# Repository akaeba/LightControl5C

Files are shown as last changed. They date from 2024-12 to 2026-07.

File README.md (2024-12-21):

# LightControl5C

Five microcontroller controlled output stages with an integrated voltage selectable power supply.

## Features
* five free programmable outputs
* up to 500mA per output (all 600mA max)
* voltage divider selectable output voltage
* optimized for 24V input voltage
* up to 20V output voltage
* inductive load capable
* ICSP programming interface
* 44mm x 27mm overall size

## Pinning
| Port | Usage |
| --- | --- |
| X1 | positive input supply, max. 28V, DC-only |
| X2 | negative input supply (GND) |
| X3 | ICSP programming |
| X4 | GND |
| X5 | open-drain uC output (GP0) |
| X6 | open-drain uC output (GP1) |
| X7 | open-drain uC output (GP2) |
| X8 | open-drain uC output (GP4) |
| X9 | open-drain uC output (GP5) |
| X10, X11 | positive supply for X5-X9, voltage via R<sub>FBT</sub> adjustable |

## How to build
* Get your PCB:
  - [Aisler](https://aisler.net/p/RHHJMNNA)
  - [PCBway](https://www.pcbway.com/project/shareproject/LightControl5C_13ccc4e5.html)
* Order Components from:
  - [Reichelt](/bom/LightControl5C_Reichelt.csv)
  - [Mouser](/bom/LightControl5C_Mouser.csv)

## Gallery
<tr>
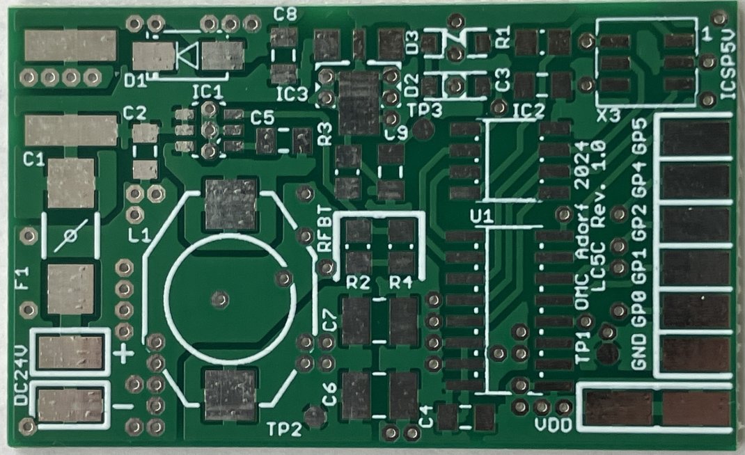
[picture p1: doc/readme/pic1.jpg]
Picture PCB Top site LightControl5C Top site
<td>  </td>
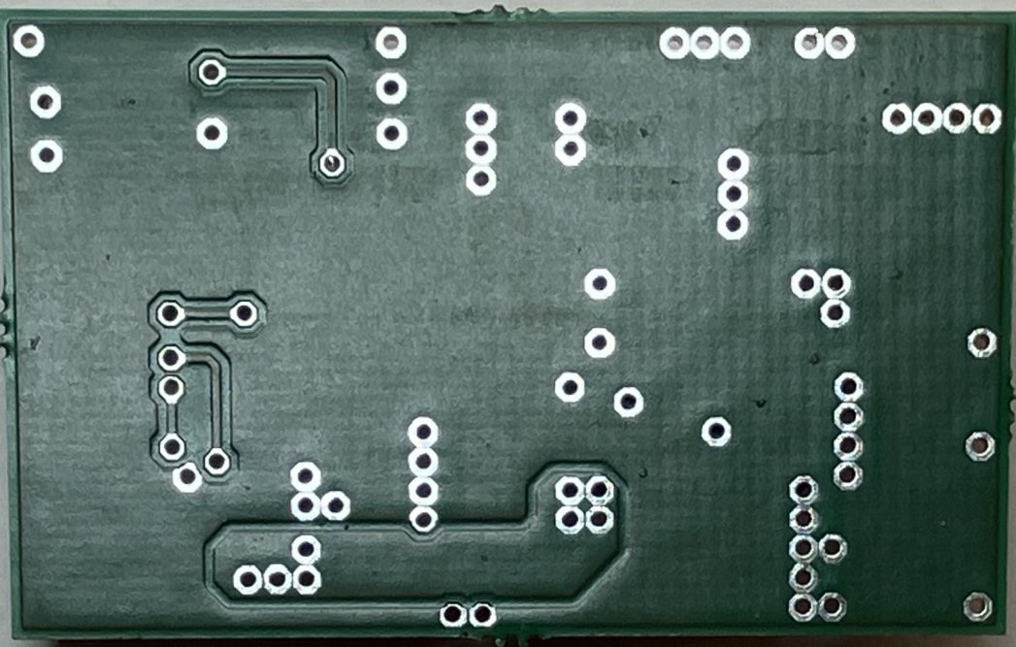
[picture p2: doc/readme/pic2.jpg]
Picture PCB Bottom site LightControl5C Bottom site
<td>  </td>
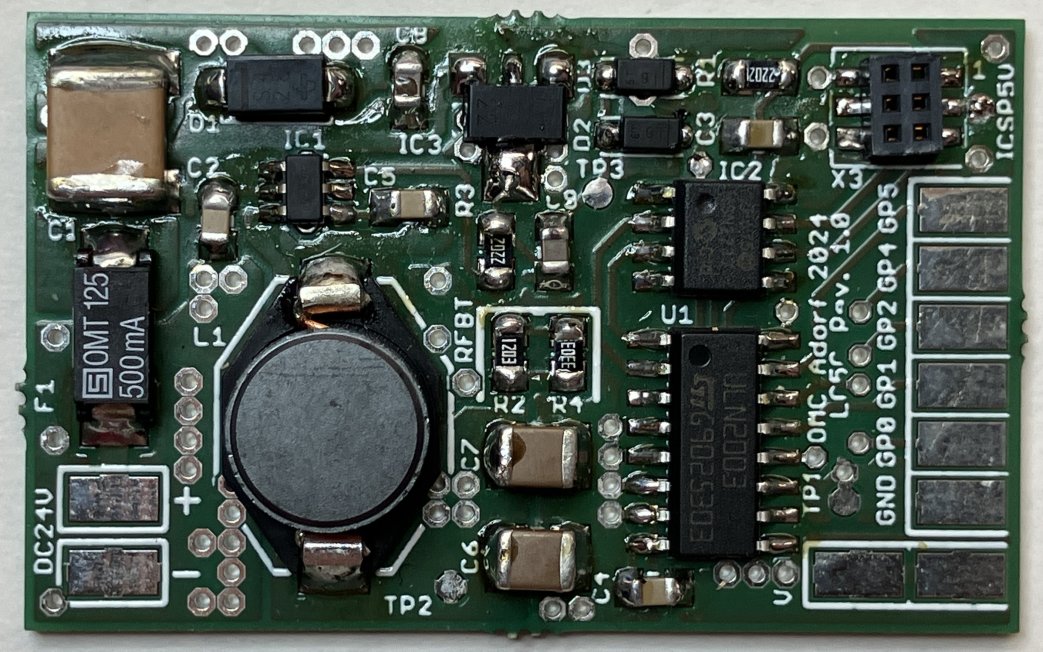
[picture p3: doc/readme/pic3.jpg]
Picture PCB with components Assembled components on LightControl5C
<td>  </td>
</tr>

## Tooling
* PCB and schematic: [Eagle 7.7](http://eagle.autodesk.com/eagle/software-versions/1)
* Compiler: [MikroC Pro for PIC 7.1](https://download.mikroe.com/setups/compilers/mikroc/pic/mikroc-pic-setup-v710.zip)
* Programmer:
  - [PicKit2 HW](https://www.microchip.com/en-us/development-tool/pg164120) - check also the clone vendors ;-)
  - [PicKit2 SW](https://ww1.microchip.com/downloads/aemDocuments/documents/OTH/ProductDocuments/SoftwareLibraries/Firmware/PICkit2v2.61.00SetupA.zip)

## References
* [LV3842: 4-V to 36-V, 600-mA, Synchronous Step-Down Converter](https://www.ti.com/lit/ds/symlink/lv3842.pdf)
* [PIC12F675: 8-Pin, Flash-Based 8-Bit CMOS Microcontrollers](https://ww1.microchip.com/downloads/aemDocuments/documents/MCU08/ProductDocuments/DataSheets/41190G.pdf)
* [ULN2003: Seven Darlington arrays](https://www.st.com/resource/en/datasheet/uln2003.pdf)
* [TPL7407LA:  30V 7-Channel Low Side Driver](https://www.ti.com/lit/ds/symlink/tpl7407la.pdf)

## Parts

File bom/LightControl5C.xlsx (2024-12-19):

Designator | Qty | Part Number | Package | Remark | Distributor
C1 | 1 | KTD500B106M55A0T00 | C2220K | SMD-Kerko, 2220, 10 µF, 50 V, 10%, MLCC | Reichelt
C2, C3, C4, C5 | 4 | 100.0nF, 0805 SMD, 50.0V | 0805 | SMD-Vielschicht-Keramikkondensator 100N, 10% | Reichelt
C6, C7 | 2 | 22.0µF, 1210 SMD, 25.0V | 1210 | Vielschicht-Kerko, 22µF, 25V, 125°C | Reichelt
C8 | 1 | 1.0µF, 0805 SMD, 50.0V | 0805 | SMD-Vielschichtkondensator G0805 - 1,0µF 50V | Reichelt
C9 | 1 | C0805C225K4RAC | 0805 | 0805, 2,2 µF, X7R, 10 %, 16V, 125°C | Reichelt
D1 | 1 | SS14-E3/61T | SMA | Schottkydiode, 40 V, 1 A, DO-214AC | Reichelt
F1 | 1 | 3404.0112.11 | OMT125 | 0,5A SMD-Sicherung, OMT-125V, träge | Reichelt
IC1 | 1 | LV3842XDBVR | SOT23-6 | 4-V to 36-V, 600mA Buck Converter in SOT-23-6 | Mouser
IC2 | 1 | PIC12F675-I/SN | SOIC8. | PIC12F675 - 8-Pin FLASH-Based 8-Bit CMOS Microcontrollers | Reichelt
 | 1 | TS78L05ACY RMG | SOT89W | Spannungsregler, fest, 5 V, SOT-89 | Reichelt
L1 | 1 | PISM-220M-04 | PISM | SMD-Power-Induktivität, PISM, Ferrit, 22µ, VDD=5V | Reichelt
R1, R3 | 2 | 22.0kΩ, 0805 SMD | 0805 | SMD-Widerstand, 0805, 22 kOhm, 125 mW, 1% | Reichelt
R2 | 1 | 120kΩ, 0805 SMD | 0805 | SMD-Widerstand, 0805, 120 kOhm, 125 mW, 1% | Reichelt
R4 | 1 | 330kΩ, 0805 SMD | 0805 | SMD-Widerstand, 0805, 330 kOhm, 125 mW, 1% | Reichelt
U1 | 1 | ULN2003D | SOIC16 | Darlington-Arrays, SO-16 | Reichelt
X3 | 1 | FLE-103-01-G-DV-TR | FLE-103 | Board to Board & Mezzanine Connectors | Mouser
D2, D3 | 2 | BAT46W | SOD123 | BAT46 - Schottky Diode | Reichelt

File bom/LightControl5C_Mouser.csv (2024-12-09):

Mouser No | Order Qty.
595-LV3842XDBVR | 1
200-FLE10301GDVTR | 1

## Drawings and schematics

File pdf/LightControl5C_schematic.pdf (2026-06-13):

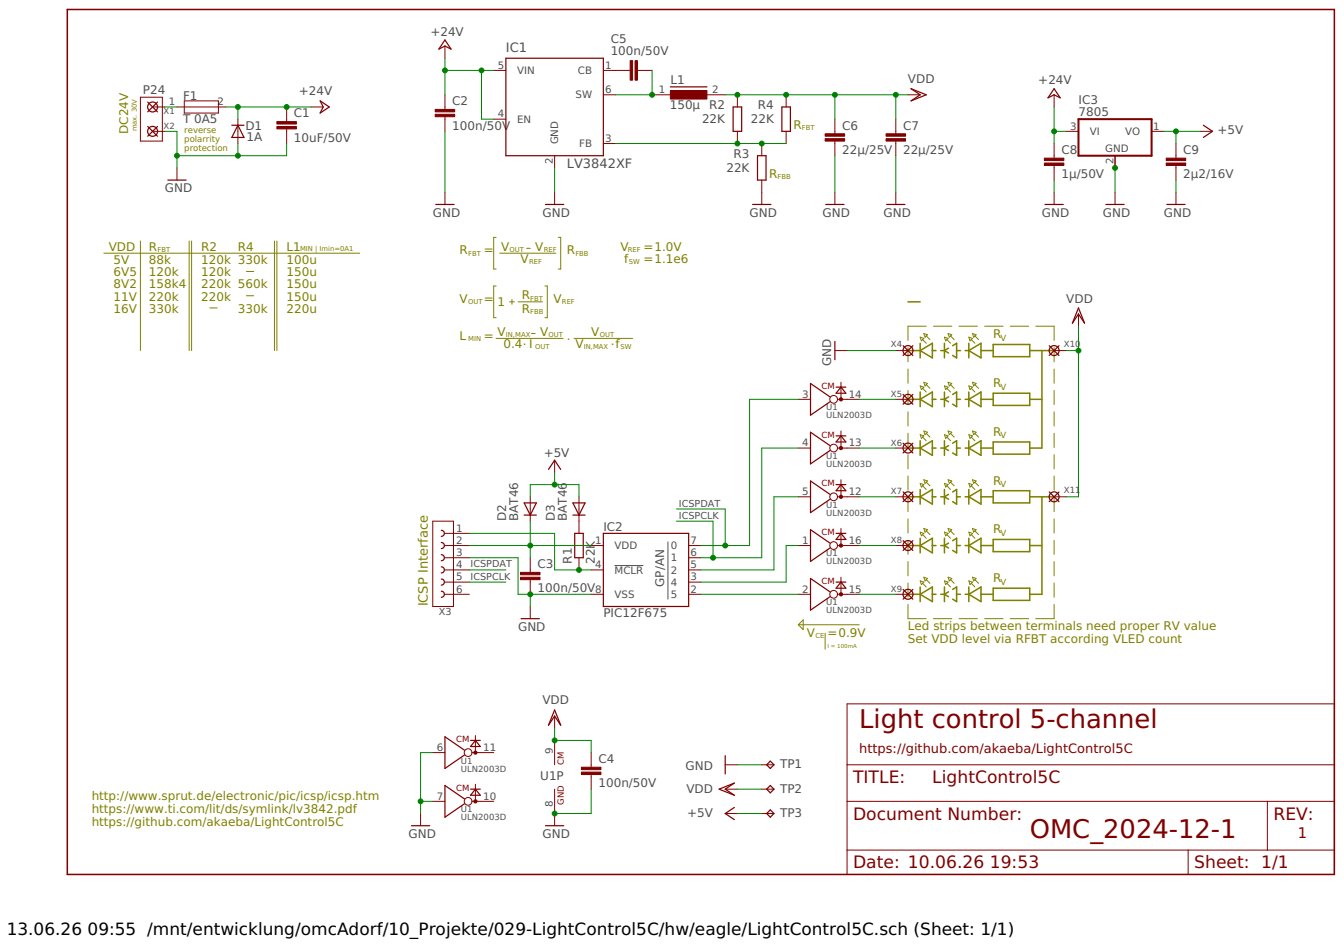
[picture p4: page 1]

reverse polarrity protection max. 30V

Led strips between terminals need proper RV value Set VDD level via RFBT according VLED count

https://github.com/akaeba/LightControl5C
TITLE:

http://www.sprut.de/electronic/pic/icsp/icsp.htm
https://www.ti.com/lit/ds/symlink/lv3842.pdf

Document Number: OMC_2024-12-1 | REV: 1

Date: 10.06.26 19:53 | Sheet: 1/1

13.06.26 09:55 /mnt/entwicklung/omcAdorf/10_Projekte/029-LightControl5C/hw/eagle/LightControl5C.sch (Sheet: 1/1)

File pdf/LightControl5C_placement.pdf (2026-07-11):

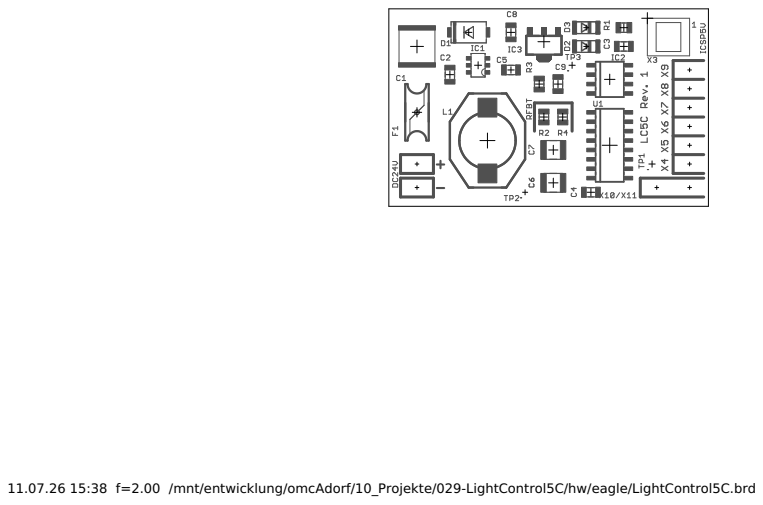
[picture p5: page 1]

11.07.26 15:38 f=2.00 /mnt/entwicklung/omcAdorf/10_Projekte/029-LightControl5C/hw/eagle/LightControl5C.brd

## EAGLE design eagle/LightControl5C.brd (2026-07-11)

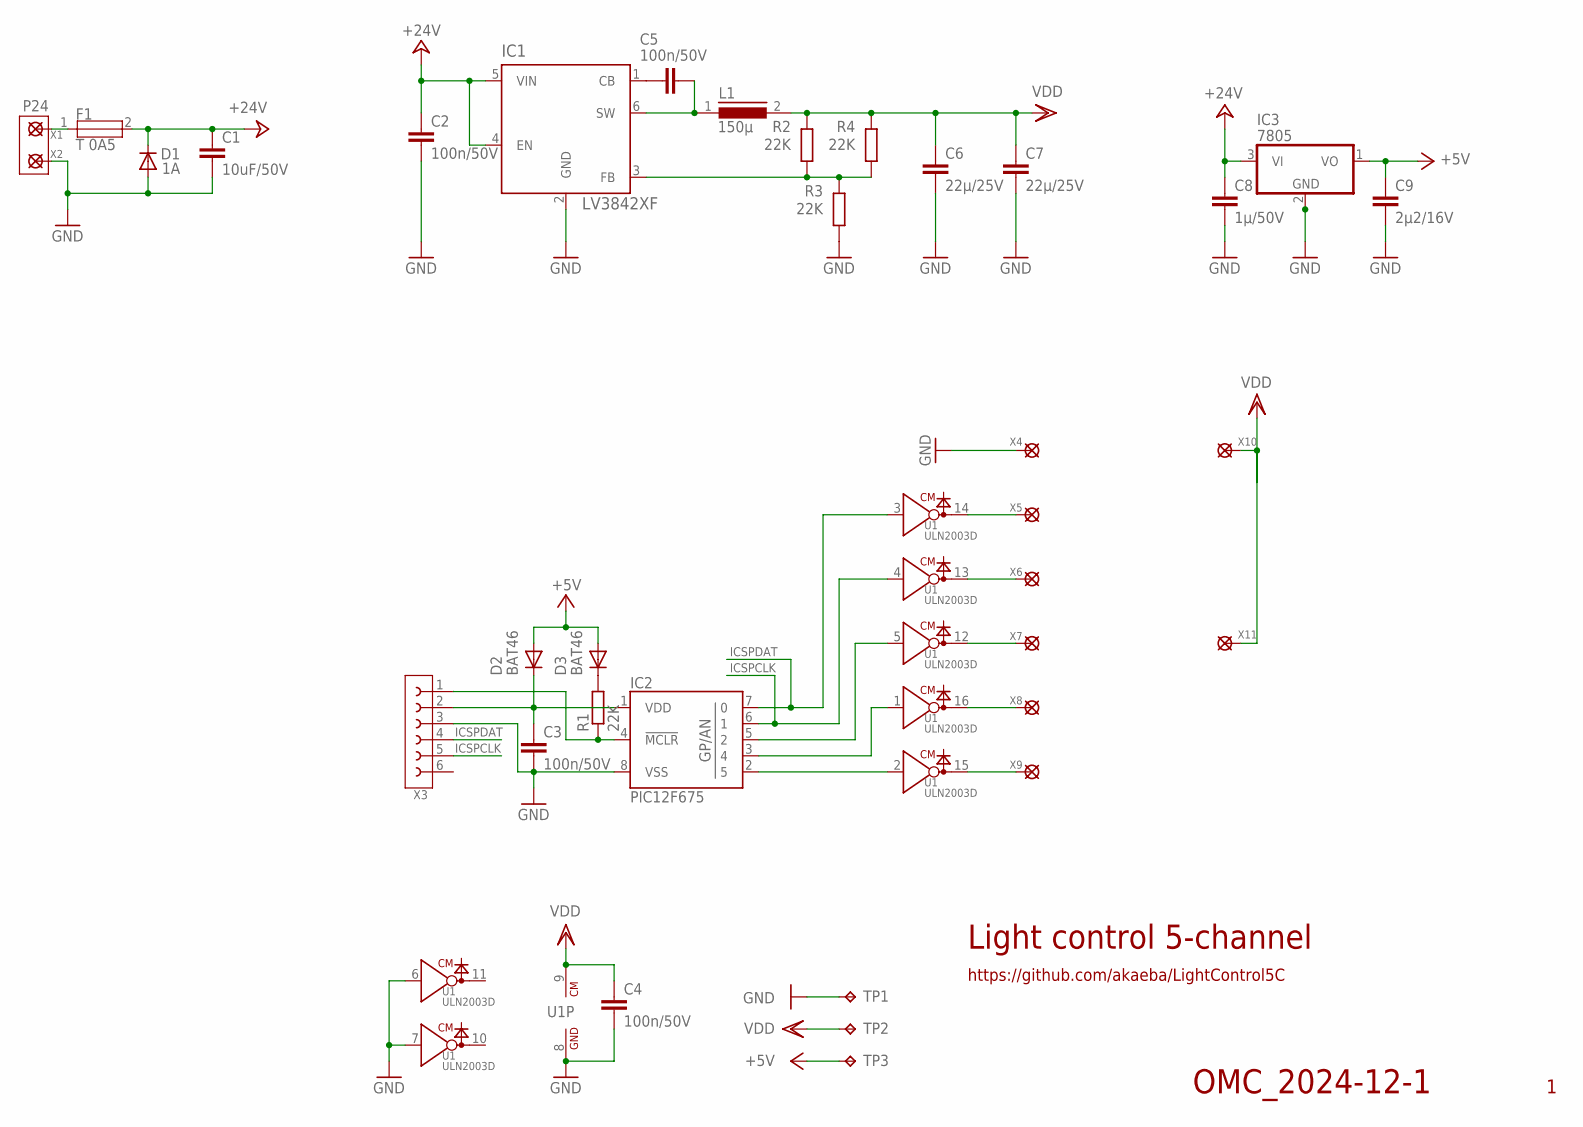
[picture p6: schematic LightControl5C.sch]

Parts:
C1: 10uF/50V; C2220K
C2, C3, C4, C5: 100n/50V; 0805
C6, C7: 22µ/25V; 1210
C8: 1µ/50V; 0805
C9: 2µ2/16V; 0805
D1: 1A; DO214AC
D2, D3: BAT46; SOD123
F1: T 0A5; OMT125
IC1: LV3842XF; SOT23-6
IC2: PIC12F675; SOIC08
IC3: 7805; SOT89W
L1: 150µ; PISM
R1, R2, R3, R4: 22K; 0805
TP1, TP2, TP3: TPB1,27; B1,27
U1: ULN2003D; SOIC16
X1, X2, X4, X5, X6, X7, X8, X9, X10, X11: Footprint; L38W19X1
X3: FLE-103-01; FLE-103

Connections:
+5V: C9.1, D2.A, D3.A, IC3.1 (VO), TP3.TP
+24V: C1.1, C2.1, C8.1, D1.C, F1.2, IC1.4 (EN), IC1.5 (VIN), IC3.3 (VI)
GND: C1.2, C2.2, C3.2, C4.2, C6.2, C7.2, C8.2, C9.2, D1.A, IC1.2 (GND), IC2.8 (VSS), IC3.2 (GND), IC3.4 (GND), R3.1, TP1.TP, U1.6 (IN), U1.7 (IN), U1.8 (GND), X2.1, X3.3, X4.1
ICSPCLK: IC2.6 (1), U1.4 (IN), X3.5
ICSPDAT: IC2.7 (0), U1.3 (IN), X3.4
unnamed: IC1.3 (FB), R2.1, R3.2, R4.1
unnamed: D3.C, R1.2
unnamed: C3.1, D2.C, IC2.1 (VDD), X3.2
unnamed: IC2.4 (!MCLR!), R1.1, X3.1
unnamed: C5.1, IC1.1 (CB)
unnamed: U1.15 (OUT), X9.1
unnamed: U1.14 (OUT), X5.1
unnamed: IC2.5 (2), U1.5 (IN)
unnamed: IC2.3 (4), U1.1 (IN)
unnamed: IC2.2 (5), U1.2 (IN)
unnamed: U1.13 (OUT), X6.1
unnamed: U1.12 (OUT), X7.1
unnamed: U1.16 (OUT), X8.1
N$SWT: C5.2, IC1.6 (SW), L1.1
P24: F1.1, X1.1
VDD: C4.1, C6.1, C7.1, L1.2, R2.2, R4.2, TP2.TP, U1.9 (CM+), X10.1, X11.1

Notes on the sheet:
Light control 5-channel
https://github.com/akaeba/LightControl5C
OMC_2024-12-1

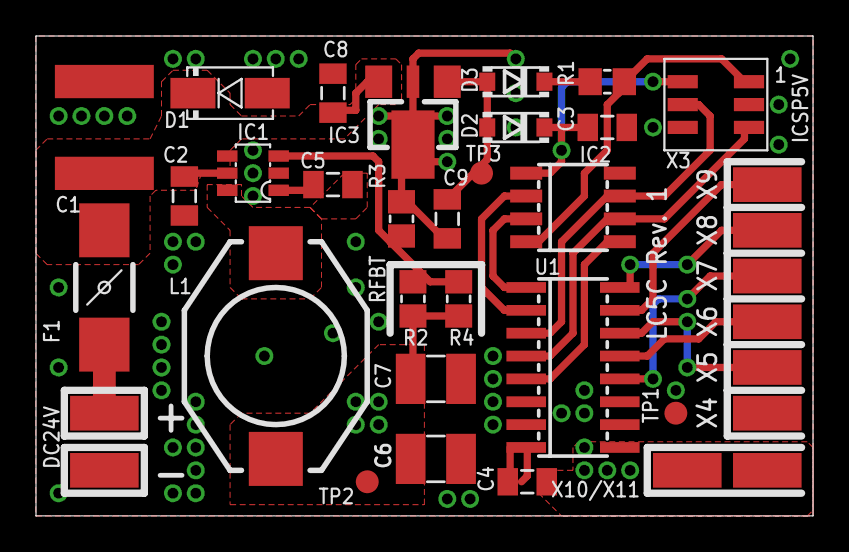
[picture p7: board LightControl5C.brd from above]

Board: 2 copper layers, 43.2 x 26.7 mm, 36 parts (0 on the bottom side), 21 nets.

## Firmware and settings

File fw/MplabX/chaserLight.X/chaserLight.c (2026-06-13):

/*************************************************************************
 * @author:     Andreas Kaeberlein
 * @copyright:  Copyright 2026
 * @credits:    AKAE
 *
 * @license:    LGPLv2.1
 * @maintainer: Andreas Kaeberlein
 * @email:      andreas.kaeberlein@web.de
 *
 * @file:       chaserLight.c
 * @date:       2026-06-13
 * @see:        https://github.com/akaeba/LightControl5C
 *
 * @brief:      chaser light
 *              running light with 500ms reside time
 *
 *              MPLAB X:  v6.25
 *              Compiler: XC8 v3.10   
 * 
 ************************************************************************/

/*
Config
======
  * INTOSC         : 4MHz no clk output
  * WDT            : disabled
  * Power Up Timer : enabled
  * GP3/MCLR       : enabled
  * Brown out      : disabled
*/


#include <xc.h>
#include <stdint.h> /* For uint8_t definitions etc */

/*define clock freq*/
#ifndef _XTAL_FREQ
  #define _XTAL_FREQ 4000000  // 4MHZ crystal
#endif

// CONFIG  PIC12F675 Configuration Bit Settings 
#pragma config FOSC = INTRCIO   // INTOSC oscillator: I/O function on GP4/OSC2/CLKOUT pin, I/O function on GP5/OSC1/CLKIN
#pragma config WDTE = OFF       // Watchdog Timer Enable bit (WDT disabled)
#pragma config PWRTE = ON       // Power-Up Timer Enable bit (PWRT enabled)
#pragma config MCLRE = ON       // GP3 is MCLR
#pragma config BOREN = OFF      // Brown-out Detect Enable bit (BOD disabled)
#pragma config CP = OFF         // Code Protection bit (Program Memory code protection is disabled)
#pragma config CPD = OFF        // Data Code Protection bit (Data memory code protection is disabled)


/* run Speed of LED */
#define  SPEED_MS  (500)


// ------- Main LOOP ---------- 
void main(void)
{
    /* init */
    TRISIO = 0B00000000;    // everything is output
    GPIO   = 0;             // all LEDs are off
    ANSEL  = 0x00;          // Set ports as digital I/O, not analog input
	ADCON0 = 0x00;          // Shut off the A/D Converter
	CMCON  = 0x07;          // Shut off the Comparator
	VRCON  = 0x00;          // Shut off the Voltage Reference    
    __delay_ms(1000);       //init delay
    
    /* infinite run */
    while(1) {
        GPIO = 0b00000001;      // GP0 enable
        __delay_ms(SPEED_MS);   // wait
        GPIO = 0b00000010;      // GP1 enable
        __delay_ms(SPEED_MS);   // wait
        GPIO = 0b00000100;      // GP2 enable
        __delay_ms(SPEED_MS);   // wait
        GPIO = 0b00010000;      // GP4 enable
        __delay_ms(SPEED_MS);   // wait
        GPIO = 0b00100000;      // GP5 enable
        __delay_ms(SPEED_MS);   // wait
    }
}
// -------- End of MAIN LOOP ---------
// EOF

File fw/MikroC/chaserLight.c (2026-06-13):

 /*************************************************************************
 @author:     Andreas Kaeberlein
 @copyright:  Copyright 2024
 @credits:    AKAE

 @license:    LGPLv2.1
 @maintainer: Andreas Kaeberlein
 @email:      andreas.kaeberlein@web.de

 @file:       lightChaser.c
 @date:       2024-07-11
 @see:        https://github.com/akaeba/LightControl5C

 @brief:      lightChaser
              running light with 500ms reside time
              IDE: mikroC Pro for PIC 7.1.0
*************************************************************************/

/*
Config
======
  * INTOSC         : 4MHz no clk output
  * WDT            : disabled
  * Power Up Timer : enabled
  * GP3/MCLR       : enabled
  * Brown out      : disabled
*/


/* run Speed of LED */
#define  SPEED_MS  (500)

/**
 *  Main
 */
void main()
{
    /* init */
    TRISIO = 0B00000000;        // everything is output
    GPIO   = 0;                 // all LEDs are off
    delay_ms(1000);             // wait 1sec for power-ramp up

    /* infinite run */
    while(1) {
        GPIO = 0b00000001;   // GP0 enable
        delay_ms(SPEED_MS);  // wait
        GPIO = 0b00000010;   // GP1 enable
        delay_ms(SPEED_MS);  // wait
        GPIO = 0b00000100;   // GP2 enable
        delay_ms(SPEED_MS);  // wait
        GPIO = 0b00010000;   // GP4 enable
        delay_ms(SPEED_MS);  // wait
        GPIO = 0b00100000;   // GP5 enable
        delay_ms(SPEED_MS);  // wait
    }
}

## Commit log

2024-12-09 PCB Cad files
    [LightControl5C.brd, LightControl5C.sch]
2024-12-09 add schematic
2024-12-09 [bom] reichelt components
    [LightControl5C_Reichelt.csv]
2024-12-09 [bom] partlist reichelt revised
    [LightControl5C_Reichelt.csv]
2024-12-09 [bom] mouser partlist
    [LightControl5C_Mouser.xls]
2024-12-09 [bom] general partlist
2024-12-09 [mouser] use csv instead of xls list
    [LightControl5C_Mouser.csv, LightControl5C_Mouser.xls]
2024-12-11 add output voltage
    [LightControl5C.sch]
2024-12-15 [eagle] add comment for Vmax for L of 22u
    [LightControl5C.sch]
2024-12-18 [doc] add link to PCBway
2024-12-19 [bom] now as excel sheet
    [LightControl5C.xlsx]
2024-12-19 [gerber] add gerber files from board
2024-12-19 [gerber] update files
2024-12-21 [fw] add example project of running leds
    [lauflicht.cfg]
2024-12-21 [doc] add link to ULN2003 FET alternative
2026-06-13 [pdf] schematic
    -> update derived docs
2026-06-13 [eagle] change inductor
    -> increase min. inductor size to allow lower currents
    [LightControl5C.brd, LightControl5C.sch]
2026-06-13 [fw] rename MikroC example
    [lauflicht.cfg, lightChaser.cfg]
2026-06-13 [fw/MikroC] rename to match with MPLAB X
    [chaserLight.cfg]
2026-07-11 [eagle] change marking
    [LightControl5C.brd]

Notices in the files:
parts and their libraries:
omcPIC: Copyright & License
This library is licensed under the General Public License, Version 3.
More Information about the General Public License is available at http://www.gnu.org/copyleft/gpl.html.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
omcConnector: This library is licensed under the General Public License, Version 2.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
